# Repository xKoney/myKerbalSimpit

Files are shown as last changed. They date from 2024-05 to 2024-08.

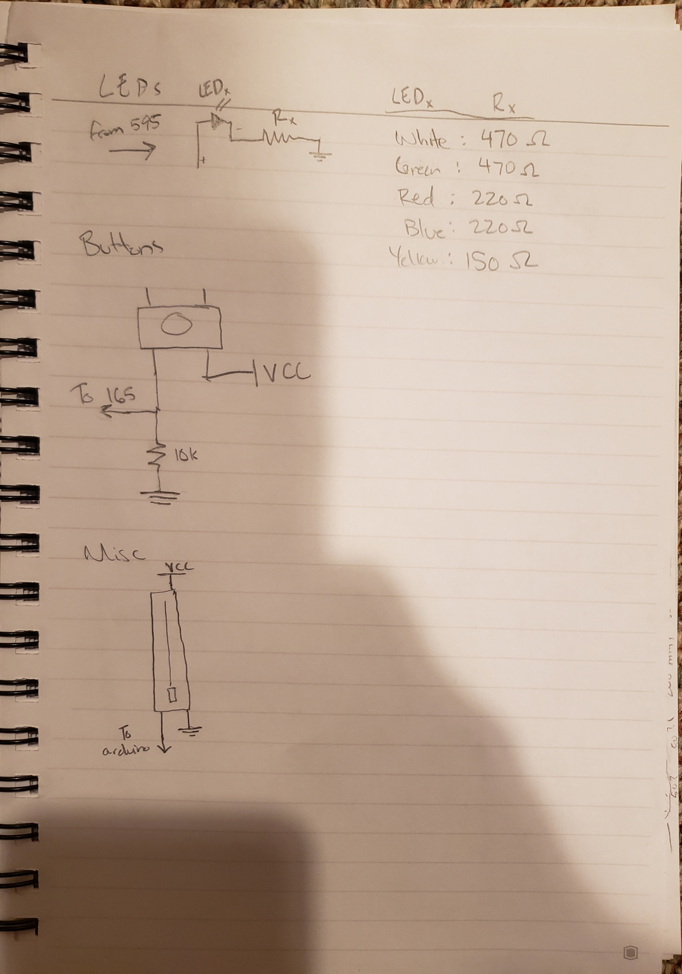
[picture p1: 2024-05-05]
Drawn Wiring Diagram 2 - Misc.jpg

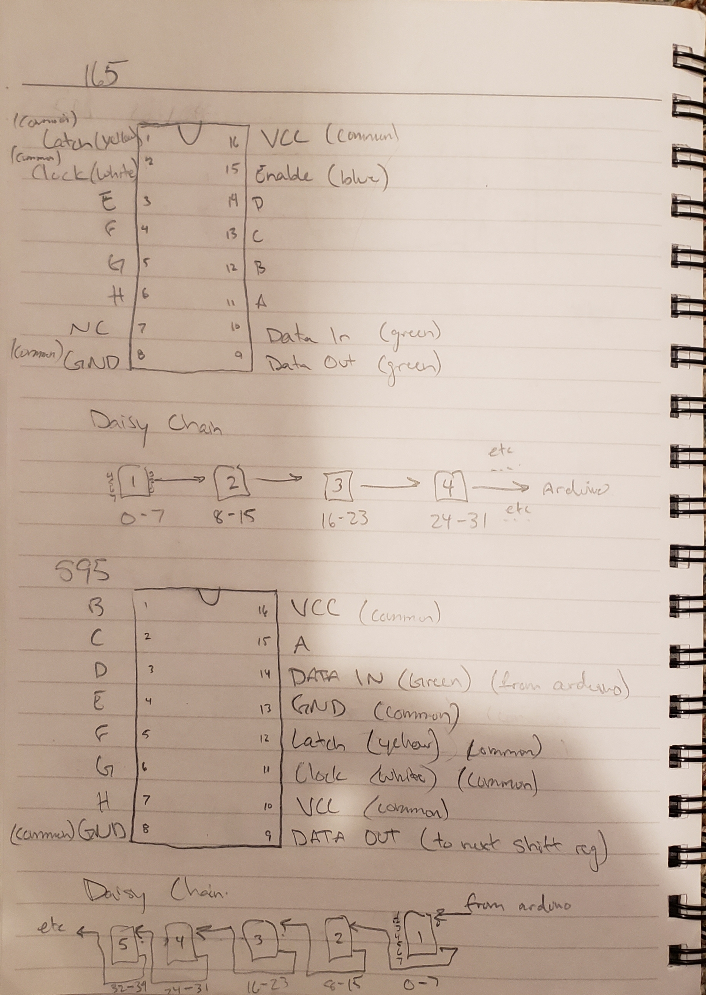
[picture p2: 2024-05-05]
Drawn Wiring Diagram 1 - Shift Registers.jpg

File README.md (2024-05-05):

# My Kerbal Controller

## Background
Here's a list of links that I referenced while creating. Some were purely inspirational, while others were copy-pasted code.

__Master Documents__

https://kerbalsimpitrevamped-arduino.readthedocs.io/en/latest/index.html

https://github.com/Simpit-team/KerbalSimpitRevamped

https://github.com/Simpit-team/KerbalSimpitRevamped-Arduino

__Build Guides and References__

https://www.instructables.com/Kerbal-Controller-the-Basics/

https://github.com/ErinaceusLinnaeus/Kontrol

https://github.com/jacobcargen/KSPController

https://github.com/c0untzer0/MyKerbalController

https://github.com/CodapopKSP/Coda-Kerbal-Controller

https://github.com/Richi0D/KerbalController-Simpit

## What is this?

This is a custom peripheral/controller that is intended for use with Kerbal Space Program (1). This utilizes a mod called KerbalSimpitRevamped, available in the Kerbal mod manager CKAN. This controller has a wide array of built-in functions like SAS mode selection, throttle controller, stage & abort arming and triggering, LED bar graph indicators for each of the fuel types, and more.

Due to the absurd amount of IOs (70+ LEDs and more than 40 buttons or joystick inputs), this project utilizes Shift Registers to minimize the amount of pins required on the Arduino. With the number of shift registers used, I decided to design a circuit board that will house all the shift registers and provide pads for soldering all the IO connections required. 

## Disclaimer

As of the writing of this READ ME, I have not completed ordering or building this controller. I believe the design is in a finalized state, but I don't have the time to pursue this project at this moment. I hope to be able to build this controller soon. That being said, it would be prudent to verify the easyEDA file before shipping to a PCB manufacturer and do some dry fit test prints of the holes and components.

Also, please forgive my terrible programming practices. This is my first programming project, and I'm a mechanical engineer, not a programmer. You'll notice a lot of commented out "test code", lack of comments, and probably some inefficient methods.

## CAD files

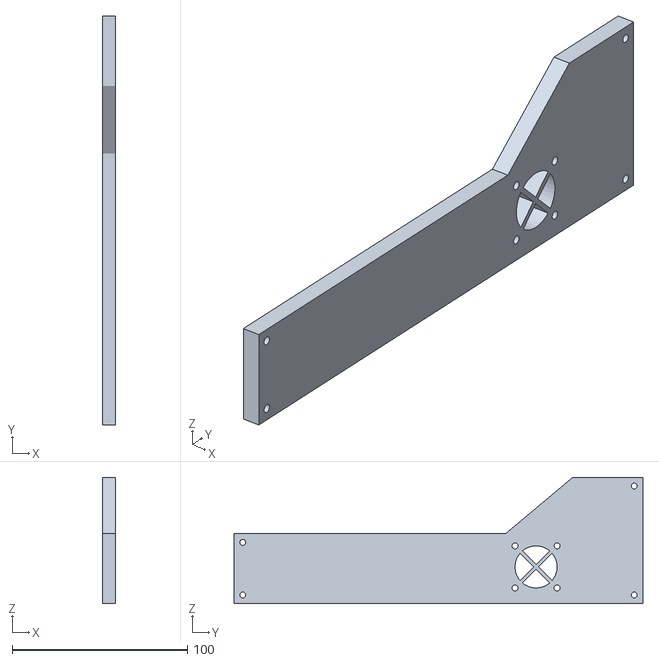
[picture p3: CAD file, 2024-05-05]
STL/Left Side Panel v8.stl
7.50 x 233.3 x 72.1

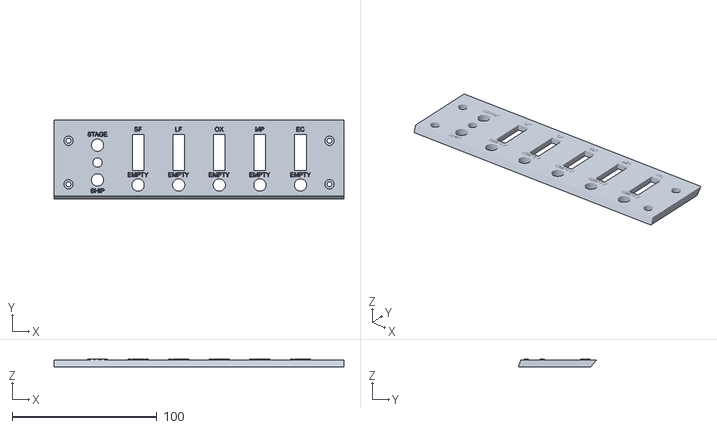
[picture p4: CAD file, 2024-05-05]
STL/Fuel Display Panel v9.stl
200.0 x 54.2 x 5.60

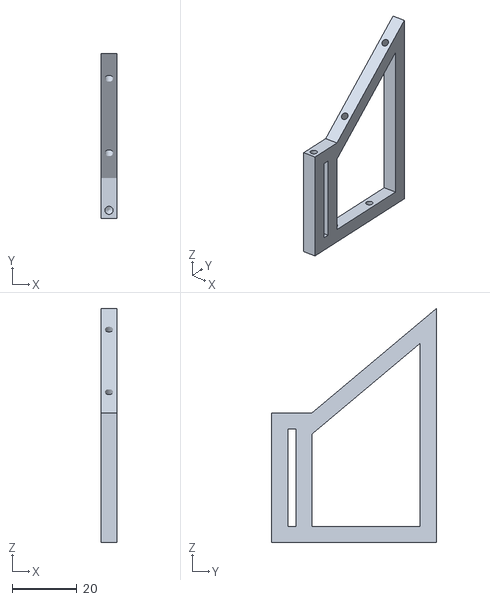
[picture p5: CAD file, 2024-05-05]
STL/Back Only Brace v5.stl
5.00 x 50.8 x 72.1

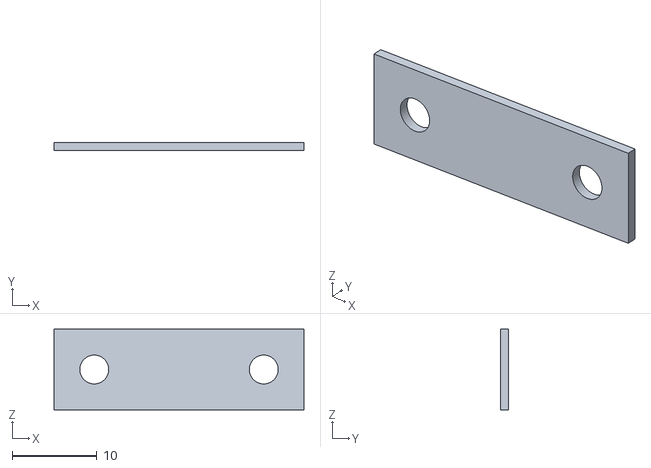
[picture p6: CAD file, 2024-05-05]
STL/Joining Plate v3.stl
29.5 x 1.00 x 9.50

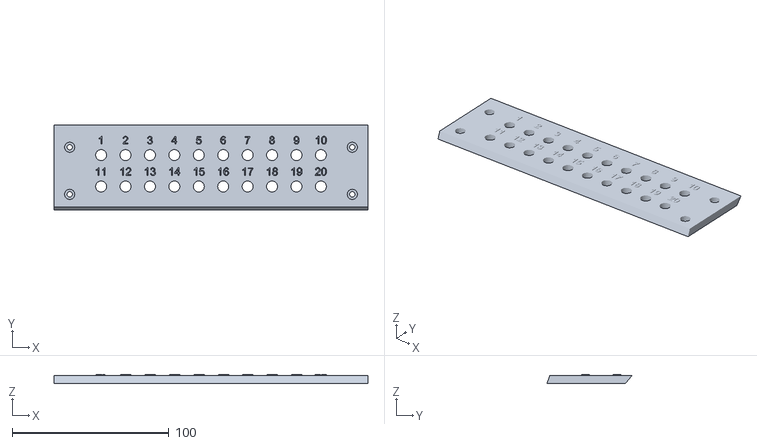
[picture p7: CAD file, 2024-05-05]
STL/Action Group Panel v8.stl
200.0 x 54.2 x 5.60

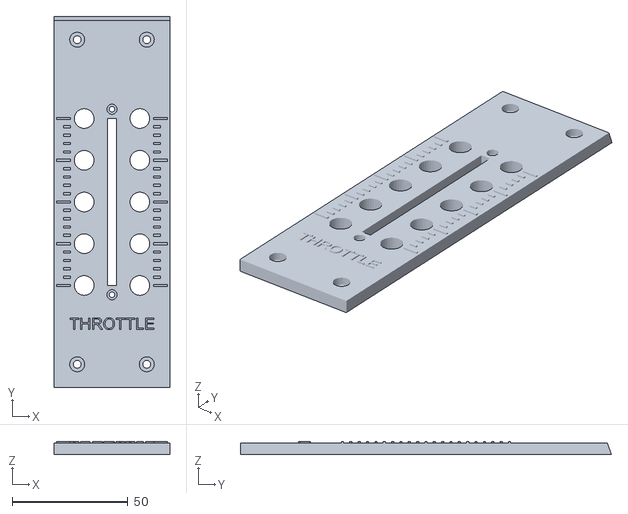
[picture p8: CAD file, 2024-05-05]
STL/Throttle Panel v5.stl
50.0 x 160.0 x 5.60

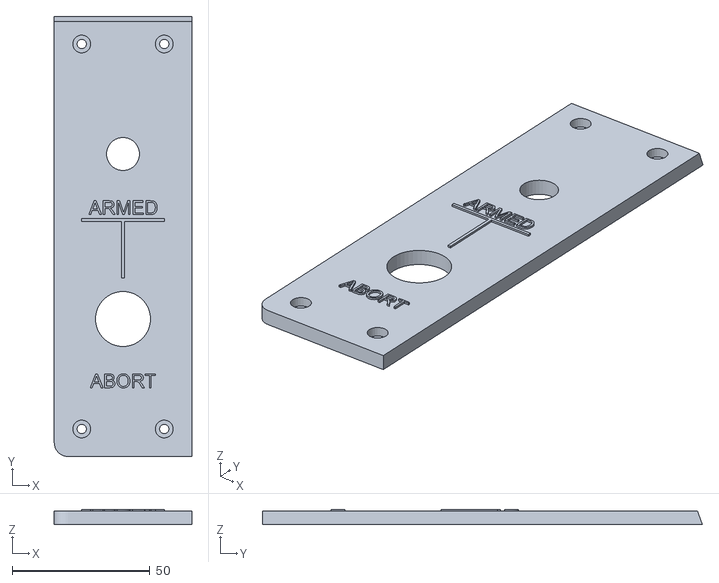
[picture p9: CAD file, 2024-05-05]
STL/Abort Panel v2.stl
50.0 x 160.0 x 5.60

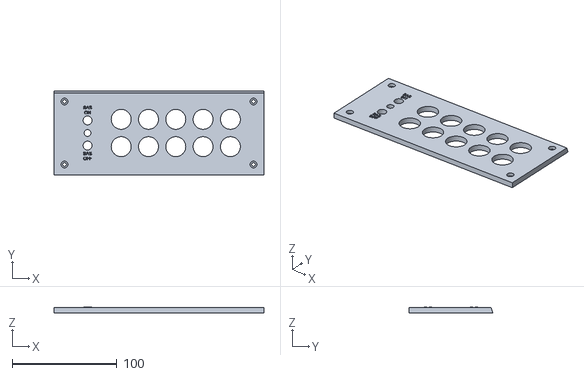
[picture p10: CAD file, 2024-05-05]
STL/SAS Plate v9.stl
200.0 x 80.0 x 5.60

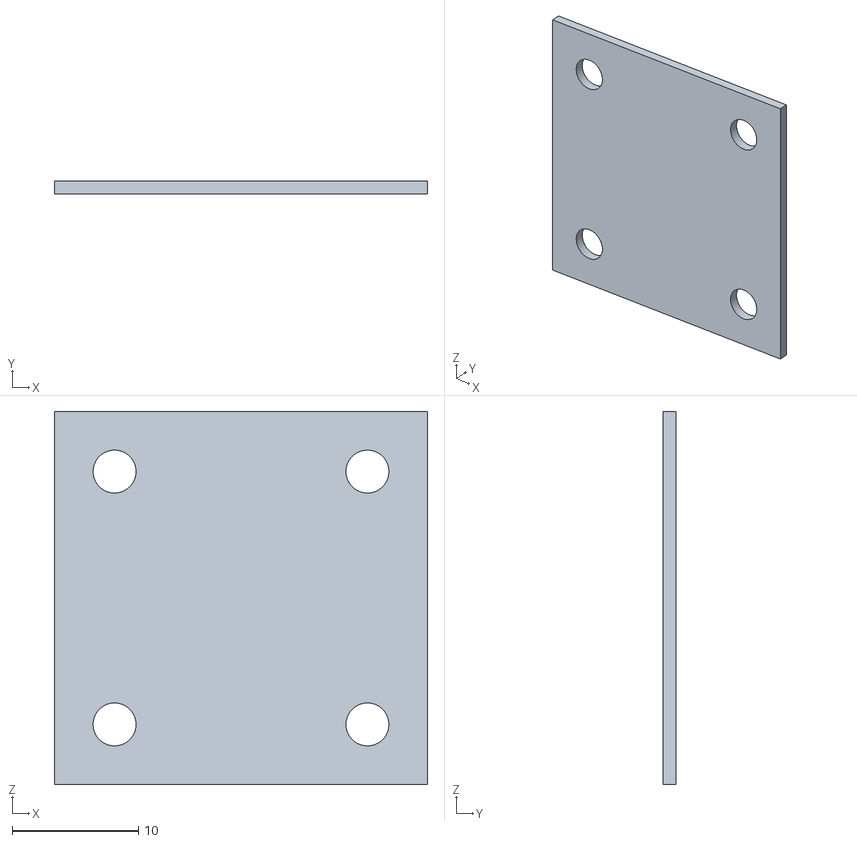
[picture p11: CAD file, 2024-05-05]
STL/Joining Plate - Large v1.stl
29.5 x 1.00 x 29.5

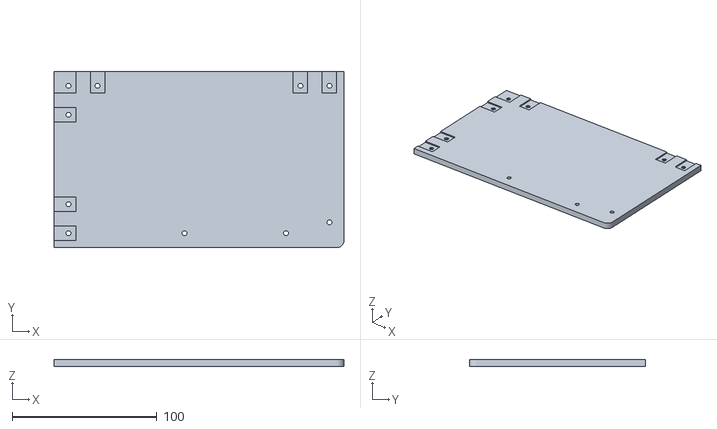
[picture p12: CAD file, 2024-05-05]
STL/Bottom Panel v7 - B.stl
200.0 x 121.7 x 5.00

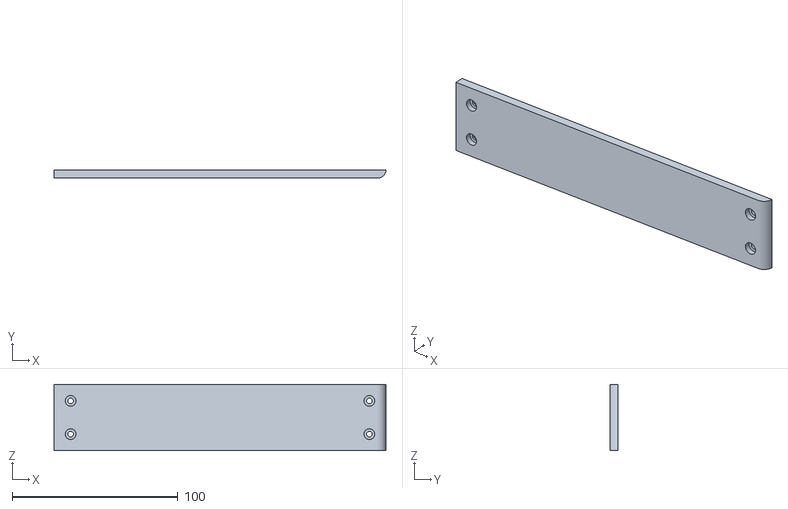
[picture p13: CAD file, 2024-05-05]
STL/Front Panel v5 - B.stl
200.0 x 5.00 x 40.0

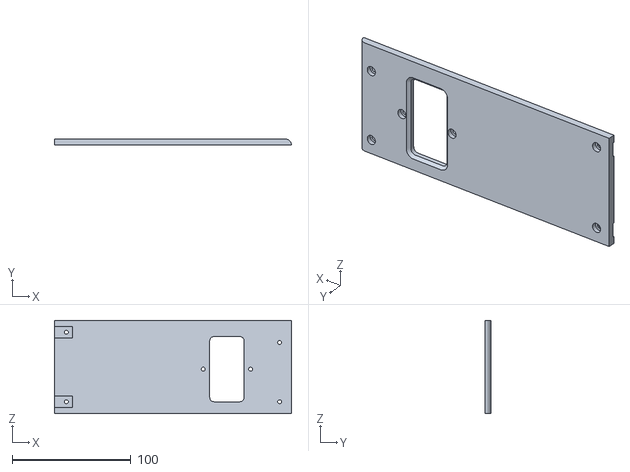
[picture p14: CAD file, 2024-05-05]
STL/Rear Panel v11 - B.stl
200.0 x 5.00 x 78.7

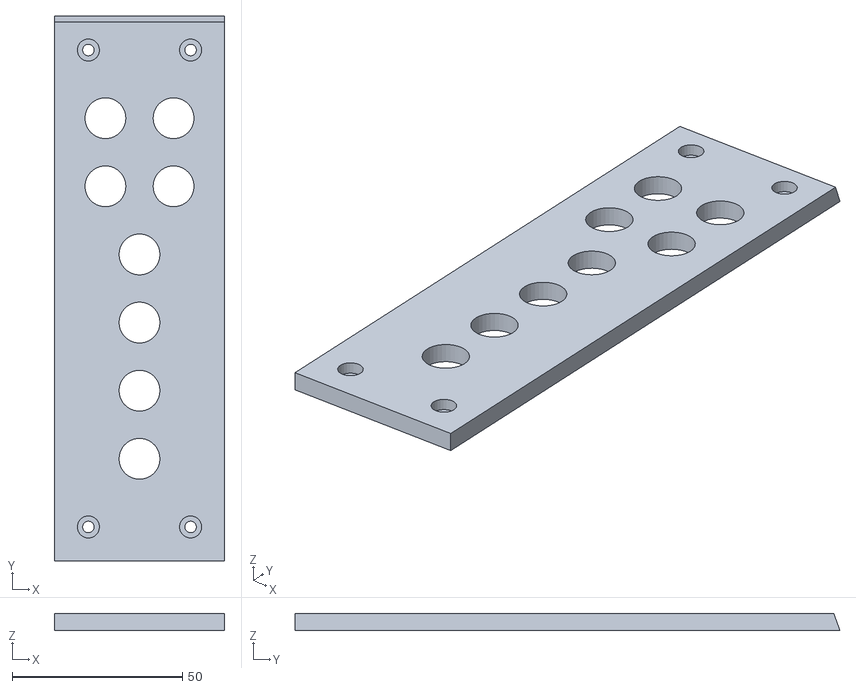
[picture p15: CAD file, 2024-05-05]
STL/Menu Panel v5.stl
50.0 x 160.0 x 5.00

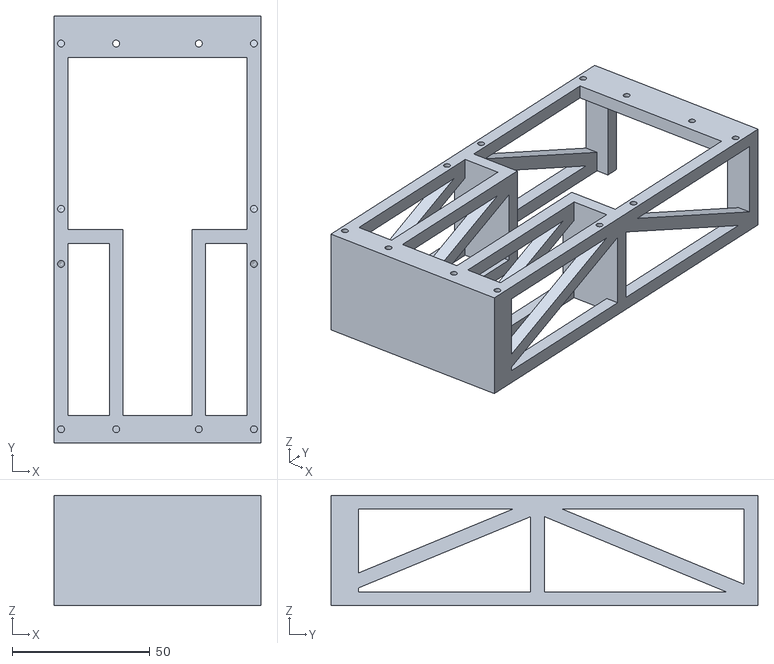
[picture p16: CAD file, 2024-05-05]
STL/Combo Brace v8.stl
75.0 x 155.0 x 40.0

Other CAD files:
STL/Right Side Panel v6.stl
STL/Top Panel v6 - B.stl
STL/Rear Panel v10 - A.stl
STL/Bottom Brace v13.stl
STL/Bottom Panel v6 - A.stl
STL/Bottom Panel v9 - D.stl
STL/Combo Brace 2 v7.stl
STL/Joystick Panel v11.stl
STL/Stage Panel v2.stl
STL/Top Panel v5 - A.stl

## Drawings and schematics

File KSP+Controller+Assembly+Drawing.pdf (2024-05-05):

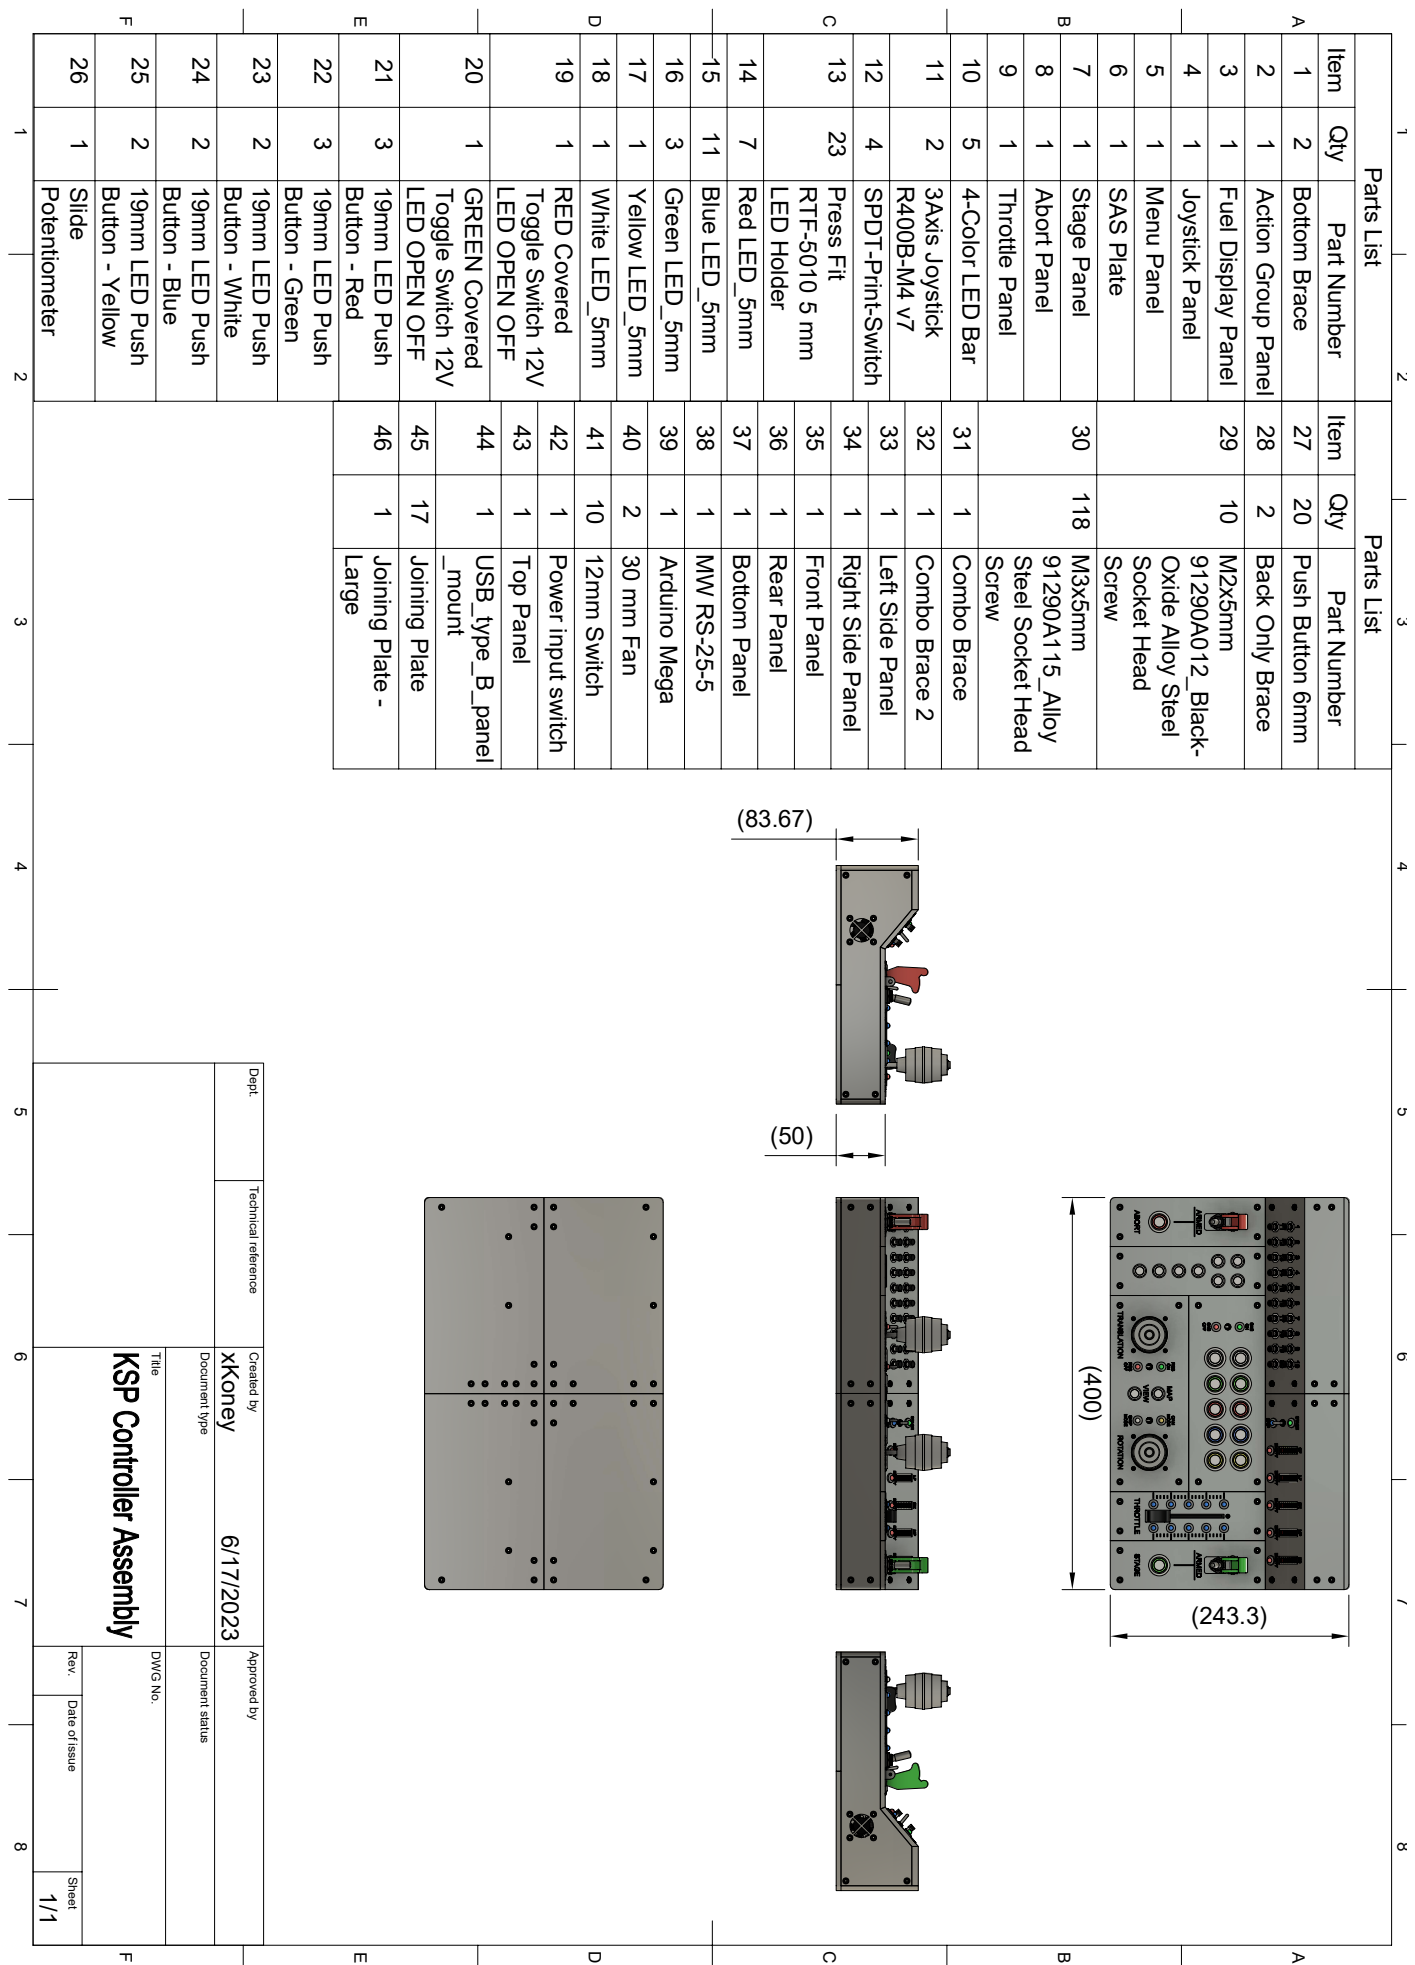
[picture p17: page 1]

A Dept. Technical reference Created by Approved by Title DWG No. Document type Document status Rev. Date of issue Sheet 6/17/2023 1/1 xKoney Parts List Item Qty Part Number 1 2 Bottom Brace 2 1 Action Group Panel 3 1 Fuel Display Panel

5 4-Color LED Bar 11 2 R400B-M4 v7 3Axis Joystick 12 4 SPDT-Print-Switch 13 23 LED Holder RTF-5010 5 mm Press Fit 14 7 Red LED_5mm 15 11 Blue LED_5mm 16 3 Green LED_5mm 17 1 Yellow LED_5mm 18 1 White LED_5mm 19 1 LED OPEN OFF Toggle Switch 12V RED Covered 20 1 LED OPEN OFF Toggle Switch 12V GREEN Covered 21 3 Button - Red 19mm LED Push 22 3 Button - Green 19mm LED Push 23 2 Button - White 19mm LED Push 24 2 Button - Blue 19mm LED Push 25 2 Button - Yellow 19mm LED Push 26 1 Potentiometer Slide Parts List Item Qty Part Number 27 20 Push Button 6mm 28 2 Back Only Brace 29 10 Screw Socket Head Oxide Alloy Steel 91290A012_Black- M2x5mm 30 118 Screw Steel Socket Head 91290A115_Alloy M3x5mm 31 1 Combo Brace 32 1 Combo Brace 2 33 1 Left Side Panel 34 1 Right Side Panel 35 1 Front Panel 36 1 Rear Panel 37 1 Bottom Panel 38 1 MW RS-25-5 39 1 Arduino Mega 40 2 30 mm Fan 41 10 12mm Switch 42 1 Power input switch 43 1 Top Panel 44 1 _mount USB_type_B_panel 45 17 Joining Plate 46 1 Large Joining Plate - (400)

4 1 Joystick Panel 5 1 Menu Panel 6 1 SAS Plate 7 1 Stage Panel 8 1 Abort Panel 9 1 Throttle Panel 10

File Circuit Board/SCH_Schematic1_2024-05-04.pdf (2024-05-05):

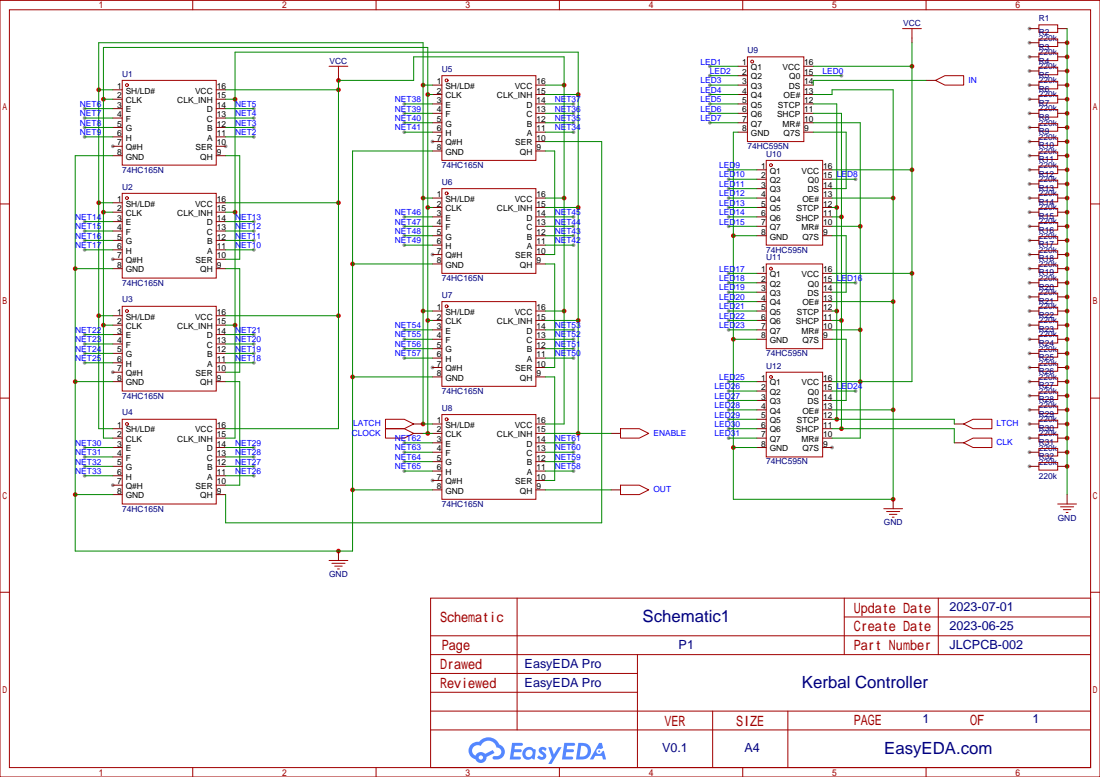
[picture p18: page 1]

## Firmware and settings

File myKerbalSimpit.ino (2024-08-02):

#include <KerbalSimpit.h>
#include <ShiftIn.h>

bool joystickDebug = false;
bool debug = false;
int cameraSensitivity = 100;

//Shift Register Declarations

//SHIFT OUT A (7 registers for output)
const int SHIFT_OUT_A_DATA = 5;
const int SHIFT_OUT_A_CLOCK = 6;
const int SHIFT_OUT_A_LATCH = 7;
bool shiftOutA[56];
int outputA;

//SHIFT OUT B (4 registers for output)
const int SHIFT_OUT_B_DATA = 2;
const int SHIFT_OUT_B_CLOCK = 3;
const int SHIFT_OUT_B_LATCH = 4;
bool shiftOutB[32];
int outputB;

//SHIFT IN A (8 registers)
const int SHIFT_IN_A_ENABLE = 10;
const int SHIFT_IN_A_DATA = 8;
const int SHIFT_IN_A_CLOCK = 9;
const int SHIFT_IN_A_LATCH = 11;

bool sasButtons[10];
bool sasButtonOld[10];
bool sasButtonChange[10];
bool changeState = false;
bool sasToggleState;
bool rcsToggleState;

byte sasCurrentMode;

timewarpMessage tw_msg;

//LED Definitions
bool abortButtonLED = false;
bool stageButtonLED = false;
bool lightsLED = false;
bool gearLED = false;
bool brakesLED = false;
bool CAG01_LED = false;
bool CAG02_LED = false;

//Button state bools
bool stageArmed;
bool abortArmed;
bool camRot;

const long blinkDelay = 500; //delay blink by 500 milliseconds
long abortSavedTime = 0;
long stageSavedTime = 0;

/* Summary of ShiftIn Button Assignments

[0] SAS Stability Assist
[1] SAS Maneuver
[2] SAS Prograde
[3] SAS Retrograde
[4] SAS Normal
[5] SAS Anti-Normal
[6] SAS Radial In
[7] SAS Radial Out
[8] SAS Target
[9] SAS Anti-Target
[10] Fuel Mode = Overall Total (TRUE) or Stage Total (FALSE)
[11] -
[12] Escape key for Pause
[13] F5 key for Quick Save
[14] F9 key for Quick Load
[15] Alt+F4 for Quit
[16] Abort Armed
[17] Abort Button
[18] Stage Armed
[19] Stage Button
[20] SAS Toggle
[21] RCS Toggle
[22] Rocket Mode vs Plane Mode (Plane Mode = HIGH ; Rocket Mode = LOW)
[23] Camera Rotation
[24] Timewarp Stop
[25] Timewarp to Next Burn (-10 seconds)
[26] Timewarp Down
[27] Timewarp Up
[28] Map
[29] View
[30] (Empty)
[31] (Empty)
[32] -
[33] -
[34] -
[35] -
[36] -
[37] -
[38] -
[39] -
[40] -
[41] -
[42] -
[43] -
[44] -
[45] -
[46] -
[47] -
[48] Lights
[49] Gear
[50] Brakes
[51] -
[52] Solar (CAG02)
[53] AG3
[54] AG4
[55] AG5
[56] AG6
[57] AG7
[58] AG8
[59] AG9
[60] AG10
[61] AG11
[62] AG12
[63] Ladder (CAG01)

*/
ShiftIn<8> shiftInA;

//0 : 0%
//1 : 25%
//2 : 50%
//3 : 75%
//4 : 100%
bool throtLED[5];

//Initialize all fuel percentages and LEDs

float sfPercent = 100;
float sfTotalOG = 0;
//0 : Empty
//1 : 10%
//2 : 20%
//3 : 30%
//4 : 40%
//5 : 50%
//6 : 60%
//7 : 70%
//8 : 80%
//9 : 90%
//10 : 100%
bool sfLEDS[11];

float lfPercent = 100;
float lfTotalOG = 0;
//0 : Empty
//1 : 10%
//2 : 20%
//3 : 30%
//4 : 40%
//5 : 50%
//6 : 60%
//7 : 70%
//8 : 80%
//9 : 90%
//10 : 100%
bool lfLEDS[11];

float oxPercent = 100;
float oxTotalOG = 0;
//0 : Empty
//1 : 10%
//2 : 20%
//3 : 30%
//4 : 40%
//5 : 50%
//6 : 60%
//7 : 70%
//8 : 80%
//9 : 90%
//10 : 100%
bool oxLEDS[11];

float mpPercent = 100;
float mpTotalOG = 0;
//0 : Empty
//1 : 10%
//2 : 20%
//3 : 30%
//4 : 40%
//5 : 50%
//6 : 60%
//7 : 70%
//8 : 80%
//9 : 90%
//10 : 100%
bool mpLEDS[11];

float ecPercent = 100;
float ecTotalOG = 0;
//0 : Empty
//1 : 10%
//2 : 20%
//3 : 30%
//4 : 40%
//5 : 50%
//6 : 60%
//7 : 70%
//8 : 80%
//9 : 90%
//10 : 100%
bool ecLEDS[11];


// 0 = Stability Assist
// 1 = Maneuver
// 2 = Prograde
// 3 = Retrograde
// 4 = Normal
// 5 = Anti-Normal
// 6 = Radial Out
// 7 = Radial In
// 8 = Target
// 9 = Anti-Target
bool sasModeLEDS[10];


bool rocketMode;
bool planeMode;
const int throttle = A0; //throttle
const int rX = A1; //rotation x-axis
const int rY = A2; //rotation y-axis
const int rZ = A3; //rotation z-axis
const int tX = A4; //translation x-axis
const int tY = A5; //translation y-axis
const int tZ = A6; //translation z-axis
int deadzoneCenter_rX = 518;
int deadzoneCenter_rY = 540;
int deadzoneCenter_rZ = 511;
int deadzoneCenter_tX = 501;
int deadzoneCenter_tY = 538;
int deadzoneCenter_tZ = 511;
int deadzone = 25;
int16_t pitch = 0; //y
int16_t roll = 0; //z
int16_t yaw = 0; //x
int16_t throt = 0; //throttle

//Store the current action status, as recevied by simpit.
byte currentActionStatus = 0;
byte myLF_TOT = 0;
byte myLF_STAGE = 0;


// Declare a KerbalSimpit object that will communicate using the "Serial" device.
KerbalSimpit mySimpit(Serial);

float LF_TOT_T = 0.0;
float LF_TOT_A = 0.0;
float percentLF_TOT = 0.0;
float LF_STAGE_T = 0.0;
float LF_STAGE_A = 0.0;
float percentLF_STAGE = 0.0;
bool TOTvSTAGE = 0;

bool totalFuel = 0;
bool stageFuel = 0;

void setup() {
  // Open the serial connection.
  Serial.begin(115200);
  shiftInA.begin(SHIFT_IN_A_LATCH,SHIFT_IN_A_ENABLE,SHIFT_IN_A_DATA,SHIFT_IN_A_CLOCK);
  // StageButton.setDebounceTime(debounceTime);

  // Set up the build in LED, and turn it on.
  pinMode(LED_BUILTIN, OUTPUT);
  //pinMode(ProgradePin, OUTPUT);
  pinMode(throttle,INPUT); //rotation x-axis
  pinMode(rX,INPUT); //rotation x-axis
  pinMode(rY,INPUT); //rotation y-axis
  pinMode(rZ,INPUT); //rotation z-axis
  pinMode(tX,INPUT); //translation x-axis
  pinMode(tY,INPUT); //translation y-axis
  pinMode(tZ,INPUT); //translation z-axis
  digitalWrite(LED_BUILTIN, HIGH);

  //Shift register pins
  pinMode(SHIFT_OUT_A_DATA, OUTPUT);
  pinMode(SHIFT_OUT_A_CLOCK, OUTPUT);
  pinMode(SHIFT_OUT_A_LATCH, OUTPUT);

  pinMode(SHIFT_OUT_B_DATA, OUTPUT);
  pinMode(SHIFT_OUT_B_CLOCK, OUTPUT);
  pinMode(SHIFT_OUT_B_LATCH, OUTPUT);

if(!joystickDebug && !debug){
  while (!mySimpit.init()) {
   delay(100);
  }
}
  // Turn off the built-in LED to indicate handshaking is complete.
  digitalWrite(LED_BUILTIN, LOW);
  // Display a message in KSP to indicate handshaking is complete.
  mySimpit.printToKSP("Connected", PRINT_TO_SCREEN);
  // Sets our callback function. The KerbalSimpit library will
  // call this function every time a packet is received.
  mySimpit.inboundHandler(messageHandler);
  // Send a message to the plugin registering for the Action status channel.
  // The plugin will now regularly send Action status  messages while the
  // flight scene is active in-game.
  mySimpit.registerChannel(ACTIONSTATUS_MESSAGE);
  mySimpit.registerChannel(SAS_MODE_INFO_MESSAGE);
  mySimpit.registerChannel(LF_MESSAGE);
  mySimpit.registerChannel(LF_STAGE_MESSAGE);
  mySimpit.registerChannel(SF_MESSAGE);
  mySimpit.registerChannel(SF_STAGE_MESSAGE);
  mySimpit.registerChannel(OX_MESSAGE);
  mySimpit.registerChannel(OX_STAGE_MESSAGE);
  mySimpit.registerChannel(MONO_MESSAGE);
  mySimpit.registerChannel(ELECTRIC_MESSAGE);
  mySimpit.registerChannel(ROTATION_MESSAGE);
  mySimpit.registerChannel(TRANSLATION_MESSAGE);
  mySimpit.registerChannel(THROTTLE_MESSAGE);
  mySimpit.registerChannel(SAS_MODE_MESSAGE);
  mySimpit.registerChannel(TIMEWARP_MESSAGE);
  mySimpit.registerChannel(CAMERA_CONTROL_MODE);
  mySimpit.registerChannel(CAMERA_ROTATION_MESSAGE);
  mySimpit.registerChannel(CAGSTATUS_MESSAGE);

//Initialize bools for various LED states
  shiftInA.getCurrent();
  totalFuel = shiftInA.state(10);
  stageFuel = !shiftInA.state(10);
  abortArmed = shiftInA.state(16);
  stageArmed = shiftInA.state(18);
  sasToggleState = shiftInA.state(20);
  rcsToggleState = shiftInA.state(21);
  planeMode = shiftInA.state(22);
  rocketMode = !shiftInA.state(22);
  camRot = shiftInA.state(23);
  lightsLED = shiftInA.state(48);
  gearLED = shiftInA.state(49);
  brakesLED = shiftInA.state(50);
  CAG01_LED = shiftInA.state(63);
  CAG02_LED = shiftInA.state(52);


  

}

void loop() {

  // Check for new serial messages.
  mySimpit.update();

analogReference(EXTERNAL);
int throtRAW = analogRead(throttle);


int analogInput = analogRead(rX);
analogInput = analogRead(rX); 

if(rocketMode){

  if((deadzoneCenter_rX - deadzone) < analogInput && analogInput < (deadzoneCenter_rX + deadzone)){
    yaw = 0;
  } else {
    yaw = constrain(map(analogInput,0,1023,INT16_MIN,INT16_MAX),INT16_MIN,INT16_MAX); //x
  }

} else if(planeMode){

  if((deadzoneCenter_rX - deadzone) < analogInput && analogInput < (deadzoneCenter_rX + deadzone)){
    roll = 0;
  } else {
    roll = constrain(map(analogInput,0,1023,INT16_MIN,INT16_MAX),INT16_MIN,INT16_MAX); //x
  }


}


analogInput = analogRead(rY);
analogInput = analogRead(rY);

if(rocketMode){
  if((deadzoneCenter_rY - deadzone) < analogInput && analogInput < (deadzoneCenter_rY + deadzone)){
    pitch = 0;
  } else {
    pitch = constrain(map(analogInput,0,1023,INT16_MIN,INT16_MAX),INT16_MIN,INT16_MAX); //y
  }
} else if(planeMode){
  if((deadzoneCenter_rY - deadzone) < analogInput && analogInput < (deadzoneCenter_rY + deadzone)){
    pitch = 0;
  } else {
    pitch = constrain(map(analogInput,0,1023,INT16_MIN+1,INT16_MAX-1),INT16_MIN,INT16_MAX); //y
    pitch *= -1; //invert
  }
}

analogInput = analogRead(rZ);
analogInput = analogRead(rZ);

if(rocketMode){

  if((deadzoneCenter_rZ - deadzone) < analogInput && analogInput < (deadzoneCenter_rZ + deadzone)){
    roll = 0;
  } else {
    roll = constrain(map(analogInput,0,1023,INT16_MIN,INT16_MAX),INT16_MIN,INT16_MAX);; //z
  }

} else if(planeMode){

  if((deadzoneCenter_rZ - deadzone) < analogInput && analogInput < (deadzoneCenter_rZ + deadzone)){
    yaw = 0;
  } else {
    yaw = constrain(map(analogInput,0,1023,INT16_MIN,INT16_MAX),INT16_MIN,INT16_MAX);; //z
  }

}

  if(!joystickDebug){
    if(camRot){
        cameraRotationMessage myCamRot;
        myCamRot.mask = 13; //send pitch, (not roll), yaw, and zoom all at once

        //Optional roll control (using left joystick for zoom)
        // myCamRot.mask = 7;

        myCamRot.cameraPitch = pitch/cameraSensitivity; //y
        if(rocketMode){
          myCamRot.cameraYaw = yaw/cameraSensitivity; //x if rocket, z if plane

          //Optional roll control (using left joystick for zoom)
          // myCamRot.cameraRoll = roll;

          myCamRot.cameraZoom = -roll/cameraSensitivity;

        } else if(planeMode){
          myCamRot.cameraYaw = roll/cameraSensitivity;

          //Optional roll control (using left joystick for zoom)
          // myCamRot.cameraRoll = yaw;

          myCamRot.cameraZoom = -yaw/cameraSensitivity;

        }
      
      mySimpit.send(CAMERA_ROTATION_MESSAGE, myCamRot);

    } else {
      rotationMessage myRot;
      myRot.mask = 7; //send pitch, yaw, and roll all at once

      myRot.pitch = pitch; //y
      myRot.yaw = yaw; //x if rocket, z if plane
      myRot.roll = roll; //z if rocket, x if plane
      mySimpit.send(ROTATION_MESSAGE, myRot);
    }
  
  }


if(rocketMode && !planeMode){

  analogInput = analogRead(tX);
  analogInput = analogRead(tX);
  int translationX = 0;
    if((deadzoneCenter_tX - deadzone) < analogInput && analogInput < (deadzoneCenter_tX + deadzone)){
      translationX = 0;
    } else {
      translationX = constrain(map(analogInput,0,1023,INT16_MIN,INT16_MAX),INT16_MIN,INT16_MAX); //x
    }

  analogInput = analogRead(tY);
  analogInput = analogRead(tY);
  int translationY = 0;
    if((deadzoneCenter_tY - deadzone) < analogInput && analogInput < (deadzoneCenter_tY + deadzone)){
      translationY = 0;
    } else {
      translationY = constrain(map(analogInput,0,1023,INT16_MIN,INT16_MAX),INT16_MIN,INT16_MAX); //y
    }

  analogInput = analogRead(tZ);
  analogInput = analogRead(tZ);
  int translationZ = 0;
    if((deadzoneCenter_tZ - deadzone) < analogInput && analogInput < (deadzoneCenter_tZ + deadzone)){
      translationZ = 0;
    } else {
      translationZ = constrain(map(analogInput,0,1023,INT16_MIN,INT16_MAX),INT16_MIN,INT16_MAX);; //z
    }

      translationMessage translation_msg;
      translation_msg.setX(translationX);
      translation_msg.setY(translationY);
      translation_msg.setZ(translationZ);
      
      if(!joystickDebug){
        if(camRot){
          //Optional zoom control using left joystick

          // cameraRotationMessage myCamRot;
          // myCamRot.mask = 8;
          // myCamRot.cameraZoom = translationZ/cameraSensitivity;
          // mySimpit.send(CAMERA_ROTATION_MESSAGE,myCamRot);
        } else {
          mySimpit.send(TRANSLATION_MESSAGE, translation_msg);
        }
      
      }
}

if(joystickDebug){
  Serial.print("tX =");
  analogRead(tX);
    Serial.println(String(analogRead(tX)));
    delay(50);
  Serial.print("tY ="); 
  analogRead(tY);
    Serial.println(String(analogRead(tY)));
        delay(50);
  Serial.print("tZ ="); 
  analogRead(tZ);
  Serial.println(String(analogRead(tZ)));
      delay(50);
    Serial.print("rX =");
    analogRead(rX);
    Serial.println(String(analogRead(rX)));
        delay(50);
  Serial.print("rY ="); 
  analogRead(rY);
    Serial.println(String(analogRead(rY)));
        delay(50);
  Serial.print("rZ ="); 
  analogRead(rZ);
  Serial.println(String(analogRead(rZ)));
      delay(50);
  delay(1500);
}

  if(throtRAW < 75){
    throtRAW = 0;
  }

  throt = map(throtRAW,0,1023,0,INT16_MAX);

  throttleMessage throttleMsg;

  throttleMsg.throttle = throt;

  mySimpit.send(THROTTLE_MESSAGE, throttleMsg);

throtLED[0] = 1;
if (throtRAW > 255){throtLED[1] = 1;}else{throtLED[1] = 0;}
if (throtRAW > 512){throtLED[2] = 1;}else{throtLED[2] = 0;}
if (throtRAW > 765){throtLED[3] = 1;}else{throtLED[3] = 0;}
if (throtRAW > 1020){throtLED[4] = 1;}else{throtLED[4] = 0;}

if(shiftInA.update()){
  
  if(shiftInA.pressed(0)){
    mySimpit.setSASMode(AP_STABILITYASSIST);
    // sasButtons[0] = 0;
  }

  if(shiftInA.pressed(1)){
    mySimpit.setSASMode(AP_MANEUVER);
    // sasButtons[1] = 0;
  }

  if(shiftInA.pressed(2)){
    mySimpit.setSASMode(AP_PROGRADE);
    // sasButtons[2] = 0;
  }

  if(shiftInA.pressed(3)){
    mySimpit.setSASMode(AP_RETROGRADE);
    // sasButtons[3] = 0;
  }

  if(shiftInA.pressed(4)){
    mySimpit.setSASMode(AP_NORMAL);
    // sasButtons[4] = 0;
  }

  if(shiftInA.pressed(5)){
    mySimpit.setSASMode(AP_ANTINORMAL);
    // sasButtons[5] = 0;
  }

  if(shiftInA.pressed(6)){
    mySimpit.setSASMode(AP_RADIALIN);
    // sasButtons[6] = 0;
  }

  if(shiftInA.pressed(7)){
    mySimpit.setSASMode(AP_RADIALOUT);
    // sasButtons[7] = 0;
  }

  if(shiftInA.pressed(8)){
    mySimpit.setSASMode(AP_TARGET);
    // sasButtons[8] = 0;
  }

  if(shiftInA.pressed(9)){
    mySimpit.setSASMode(AP_ANTITARGET);
    // sasButtons[9] = 0;
  }

  if(shiftInA.state(10) && shiftInA.pressed(10)){
    totalFuel = true;
    stageFuel = false;
  }

  if(shiftInA.released(10) && !shiftInA.state(10)){
    totalFuel = false;
    stageFuel = true;
  }


  //Pin 11

  if(shiftInA.pressed(12)){
    keyboardEmulatorMessage keyMsg(0x1B);
    mySimpit.send(KEYBOARD_EMULATOR,keyMsg);
    // Pause ESC = 0x1B
  }

  if(shiftInA.pressed(13)){
    keyboardEmulatorMessage keyMsg(0x74);
    mySimpit.send(KEYBOARD_EMULATOR,keyMsg);
    // Save F5 = 0x74
  }

  if(shiftInA.pressed(14)){
    keyboardEmulatorMessage keyMsg(0x78);
    keyMsg.modifier = KEY_DOWN_MOD;
    mySimpit.send(KEYBOARD_EMULATOR,keyMsg);
    delay(2000); //press and hold for 2 seconds
    keyMsg.modifier = KEY_UP_MOD;
    mySimpit.send(KEYBOARD_EMULATOR,keyMsg);
    // Load F9 = 0x78
  }

  if(shiftInA.pressed(15)){
    keyboardEmulatorMessage keyMsg(0x73,ALT_MOD);
    mySimpit.send(KEYBOARD_EMULATOR,keyMsg);
    // Quit ALT+F4 = 0x73
  }

  if(shiftInA.state(16) && shiftInA.pressed(16)){
    abortArmed = true;
    abortButtonLED = true;
    abortSavedTime = millis();
  }

  if(shiftInA.released(16) && !shiftInA.state(16)){
    abortArmed = false;
    abortButtonLED = false;
  }

  if(shiftInA.pressed(17) && abortArmed){
    mySimpit.activateAction(ABORT_ACTION);
  }

  if(shiftInA.state(18) && shiftInA.pressed(18)){
    stageArmed = true;
    stageButtonLED = true;
    stageSavedTime = millis();
  }

  if(shiftInA.released(18) && !shiftInA.state(18)){
    stageArmed = false;
    stageButtonLED = false;
  }

  if(shiftInA.pressed(19) && stageArmed){
    mySimpit.activateAction(STAGE_ACTION);
  }

  if(shiftInA.state(20) && shiftInA.pressed(20)){
    sasToggleState = true;
    mySimpit.activateAction(SAS_ACTION);
  }

  if(shiftInA.released(20) && !shiftInA.state(20)){
    sasToggleState = false;
    mySimpit.deactivateAction(SAS_ACTION);
  }  

  if(shiftInA.state(21) && shiftInA.pressed(21)){
    rcsToggleState = true;
    mySimpit.activateAction(RCS_ACTION);
  }

  if(shiftInA.released(21) && !shiftInA.state(21)){
    rcsToggleState = false;
    mySimpit.deactivateAction(RCS_ACTION);
  }  

  if(shiftInA.state(22) && shiftInA.pressed(22)){
    planeMode = true;
    rocketMode = false;
  }

  if(shiftInA.released(22) && !shiftInA.state(22)){
    rocketMode = true;
    planeMode = false;
  }

  if(shiftInA.state(23) && shiftInA.pressed(23)){
    camRot = true;
  }

  if(shiftInA.released(23) && !shiftInA.state(23)){
    camRot = false;
  }

  if(shiftInA.pressed(24)){
    tw_msg.command = TIMEWARP_CANCEL_AUTOWARP;
    mySimpit.send(TIMEWARP_MESSAGE,tw_msg);
  } 

  if(shiftInA.pressed(25)){
    timewarpToMessage twTo_msg(TIMEWARP_TO_NEXT_BURN,-10);
    mySimpit.send(TIMEWARP_MESSAGE,twTo_msg);
  } 

  if(shiftInA.pressed(26)){
    tw_msg.command = TIMEWARP_DOWN;
    mySimpit.send(TIMEWARP_MESSAGE,tw_msg);
  }

  if(shiftInA.pressed(27)){
    tw_msg.command = TIMEWARP_UP;
    mySimpit.send(TIMEWARP_MESSAGE,tw_msg);
  }

  if(shiftInA.pressed(28)){
    keyboardEmulatorMessage keyMsg(0x4D);
    mySimpit.send(KEYBOARD_EMULATOR,keyMsg);
    // M = 0x4D
  } 

  if(shiftInA.pressed(29)){
    keyboardEmulatorMessage keyMsg(0x56);
    mySimpit.send(KEYBOARD_EMULATOR,keyMsg);
    // V = 0x56
  } 

  if(shiftInA.pressed(30)){
    //keyboardEmulatorMessage keyMsg(0x56);
    //mySimpit.send(KEYBOARD_EMULATOR,keyMsg);
    // V = 0x56
  } 

  if(shiftInA.pressed(31)){
    //keyboardEmulatorMessage keyMsg(0x56);
    //mySimpit.send(KEYBOARD_EMULATOR,keyMsg);
    // V = 0x56
  } 

  if(shiftInA.state(48) && shiftInA.pressed(48)){
    lightsLED = true;
    mySimpit.activateAction(LIGHT_ACTION);
  }

  if(shiftInA.released(48) && !shiftInA.state(48)){
    lightsLED = false;
    mySimpit.deactivateAction(LIGHT_ACTION);
  }  

  if(shiftInA.state(49) && shiftInA.pressed(49)){
    gearLED = true;
    mySimpit.activateAction(GEAR_ACTION);
  }

  if(shiftInA.released(49) && !shiftInA.state(49)){
    gearLED = false;
    mySimpit.deactivateAction(GEAR_ACTION);
  }  

  if(shiftInA.state(50) && shiftInA.pressed(50)){
    brakesLED = true;
    mySimpit.activateAction(BRAKES_ACTION);
  }

  if(shiftInA.released(50) && !shiftInA.state(50)){
    brakesLED = false;
    mySimpit.deactivateAction(BRAKES_ACTION);
  }  

  if(shiftInA.state(63) && shiftInA.pressed(63)){
    CAG01_LED = true;
    mySimpit.activateCAG(1);
  }

  if(shiftInA.released(63) && !shiftInA.state(63)){
    CAG01_LED = false;
    mySimpit.deactivateCAG(1);
  }  

  if(shiftInA.state(52) && shiftInA.pressed(52)){
    CAG02_LED = true;
    mySimpit.activateCAG(2);
  }

  if(shiftInA.released(52) && !shiftInA.state(52)){
    CAG02_LED = false;
    mySimpit.deactivateCAG(2);
  }  

  if(shiftInA.pressed(53)){
    mySimpit.toggleCAG(3);
  }  

  if(shiftInA.pressed(54)){
    mySimpit.toggleCAG(4);
  } 

  if(shiftInA.pressed(55)){
    mySimpit.toggleCAG(5);
  } 

  if(shiftInA.pressed(56)){
    mySimpit.toggleCAG(6);
  } 

  if(shiftInA.pressed(57)){
    mySimpit.toggleCAG(7);
  } 

  if(shiftInA.pressed(58)){
    mySimpit.toggleCAG(8);
  } 

  if(shiftInA.pressed(59)){
    mySimpit.toggleCAG(9);
  } 

  if(shiftInA.pressed(60)){
    mySimpit.toggleCAG(10);
  } 

  if(shiftInA.pressed(61)){
    mySimpit.toggleCAG(11);
  } 

  if(shiftInA.pressed(62)){
    mySimpit.toggleCAG(12);
  }   

}

//Stage & Abort LED Blink
if(stageArmed && millis() - stageSavedTime >= blinkDelay){
  stageButtonLED = !stageButtonLED;
  stageSavedTime = millis();
}
if(abortArmed && millis() - abortSavedTime >= blinkDelay){
  abortButtonLED = !abortButtonLED;
  abortSavedTime = millis();
}

setOutputValues();
sendShiftOut(shiftOutA,SHIFT_OUT_A_DATA,SHIFT_OUT_A_LATCH,SHIFT_OUT_A_CLOCK);
sendShiftOut(shiftOutB,SHIFT_OUT_B_DATA,SHIFT_OUT_B_LATCH,SHIFT_OUT_B_CLOCK);    // sendShiftOut(testArray,SHIFT_OUT_A_DATA,SHIFT_OUT_A_LATCH,SHIFT_OUT_A_CLOCK);

}
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

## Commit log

2024-05-04 Add files via upload
    **Additional Files Uploaded**
    Custom circuit board for all connections and the shift registers
    Added easyEDA file for circuit board design
    Added Gerber files of exported circuit board
    3D printed files added
    Exported STL files of all 3D printed parts
    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
    [Abort Panel v2.stl, Action Group Panel v8.stl, Back Only Brace v5.stl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]
2024-05-06 Updated Shift Register related setup to match PCB
2024-07-31 fixed plane mode pitch
    [myKerbalSimpit.ino]
2024-08-02 fix for Quick Load
    [myKerbalSimpit.ino]
